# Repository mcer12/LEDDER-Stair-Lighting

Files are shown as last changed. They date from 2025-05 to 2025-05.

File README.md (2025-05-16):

## LEDDER - Motion Triggered Stair Lighting
This was a personal project of mine to make motion triggered stair lights. It uses custom designed PCBs and 3D models, so I wouldn't call it beginner friendly. Feel free to use any of this for your own project.

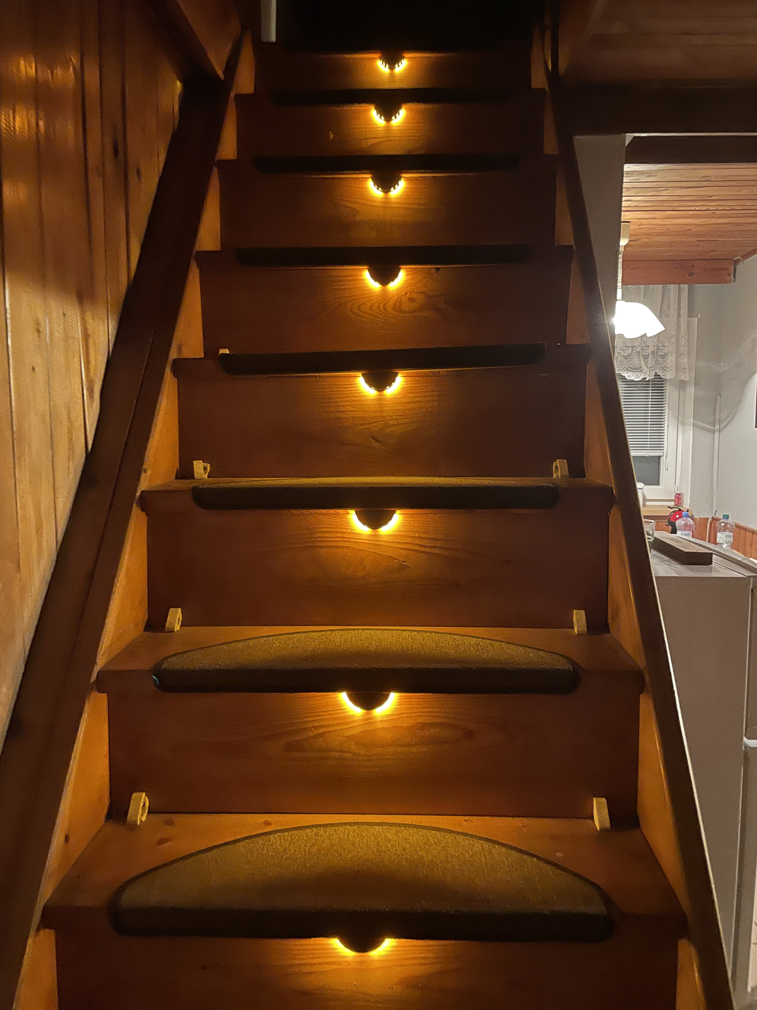
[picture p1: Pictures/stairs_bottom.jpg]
Your image title


### Main points of this project
- Very warm, 2000K LEDs ([C5440671](https://lcsc.com/product-detail/LED-Indication-Discrete_XINGLIGHT-XL-3806WWC_C5440671.html?s_z=n_C5440671%2520)) were chosen for cozy feel and to not be harsh on the eyes at night
- Slow fade-in fade-out, dimming is also gamma corrected so it's nicely linear
- Two sensors so it can be triggered when approaching any side of the stairs.
- Motion sensors combined with photoresistors for triggering only when it's dark
- Fuse not only on the control board but also on every step light, each sensor. Safety first.

### Requirements (apart from PCBs, PCB compontents and 3D printing)
- Power supply used is 12V MeanWell LRS-75-12 (the case has screw positions for it)
- 12x M3x5 hot-melt inserts
- 6x M2x5 hot-melt inserts
- 2x M20x1.5 cable gland

### Some notes
- Each light PCB is designed to be broken apart into two half-circle boards
- Two variants of light PCB are added (for 3806 LEDs and for 4008 LEDs), choose 3806 version for the recommended amber LEDs.
- See images to get better idea of how this looks and works

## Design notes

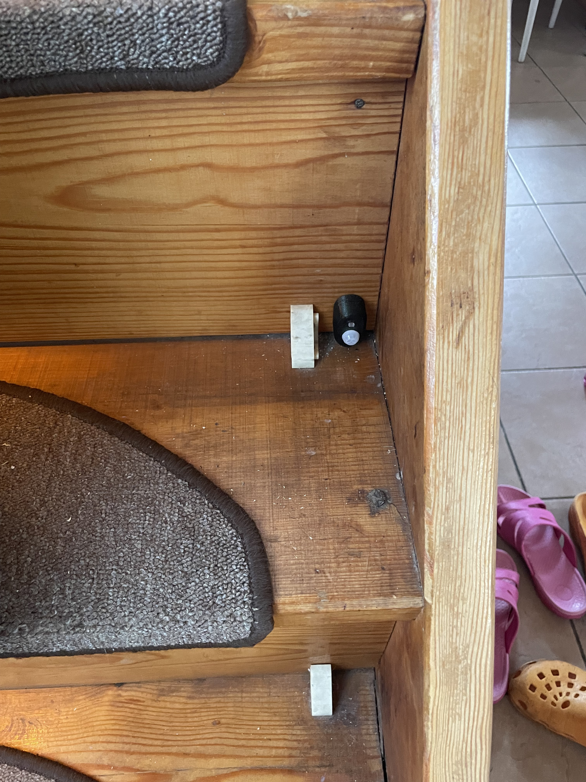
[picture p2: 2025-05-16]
Pictures/imagy-image (6).jpg

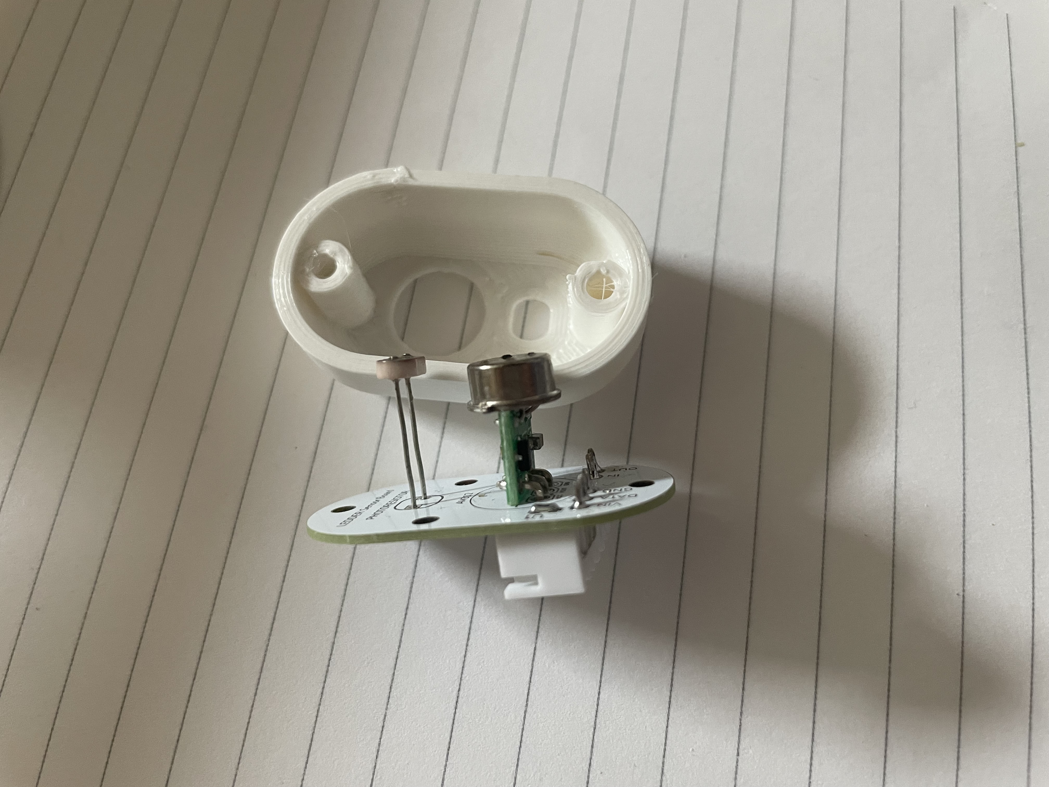
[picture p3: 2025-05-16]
Pictures/imagy-image (3).jpg

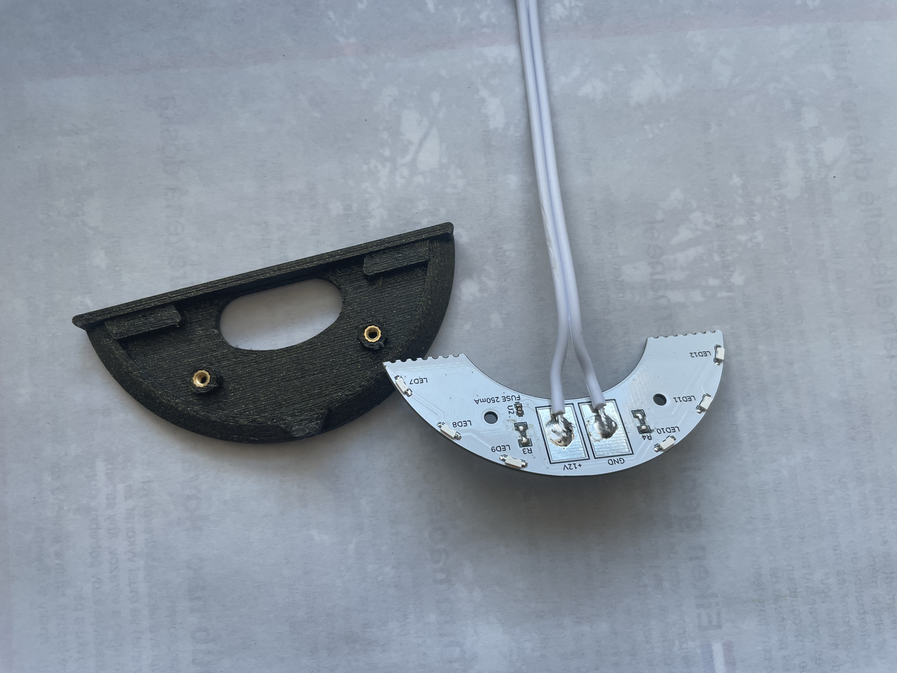
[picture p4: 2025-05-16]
Pictures/imagy-image (1).jpg

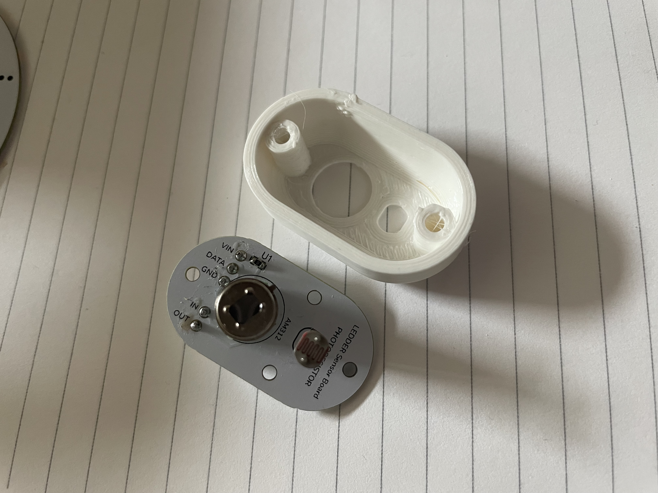
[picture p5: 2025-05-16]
Pictures/imagy-image (2).jpg

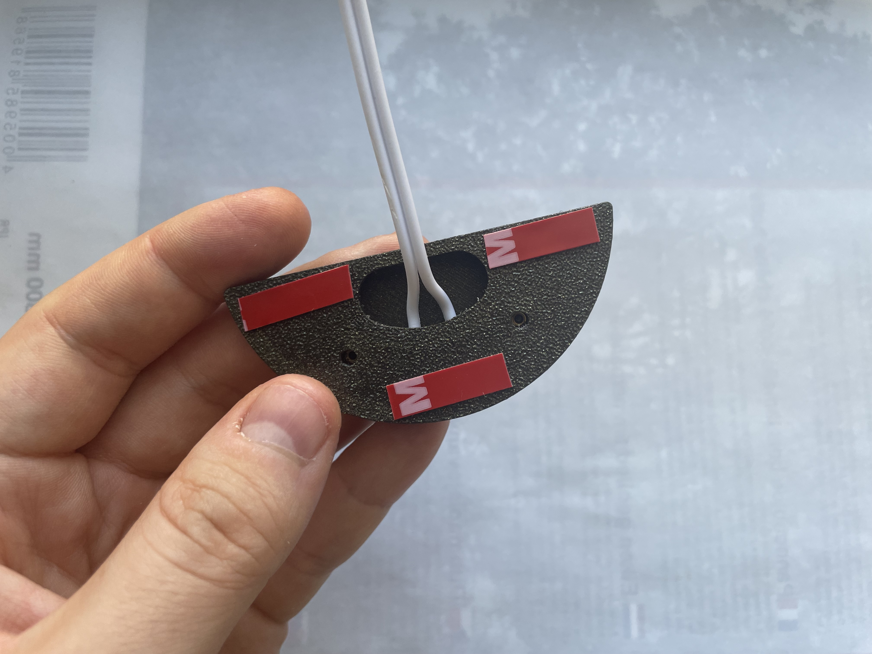
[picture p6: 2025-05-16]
Pictures/imagy-image (4).jpg

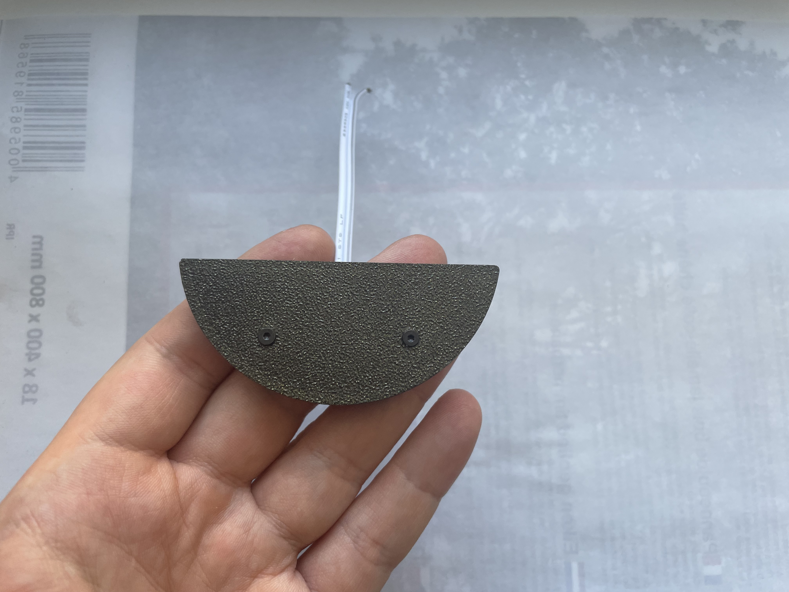
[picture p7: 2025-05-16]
Pictures/imagy-image.jpg

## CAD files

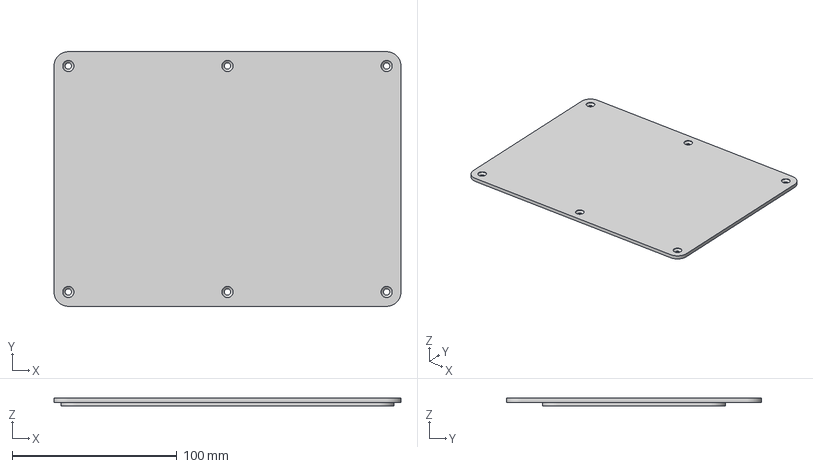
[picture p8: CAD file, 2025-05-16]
Parts/Driver Board/3D Models/box_lid.3mf
210.4 x 154.4 x 4.80 mm

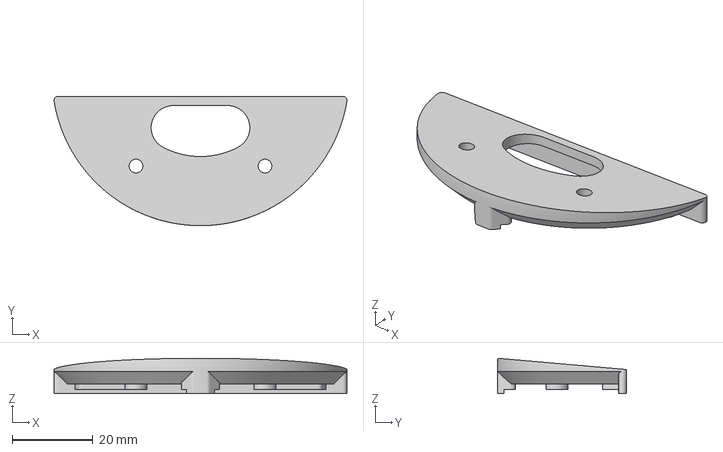
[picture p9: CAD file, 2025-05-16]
Parts/Light/3D Models/light_bottom.3mf
72.7 x 32.1 x 8.80 mm

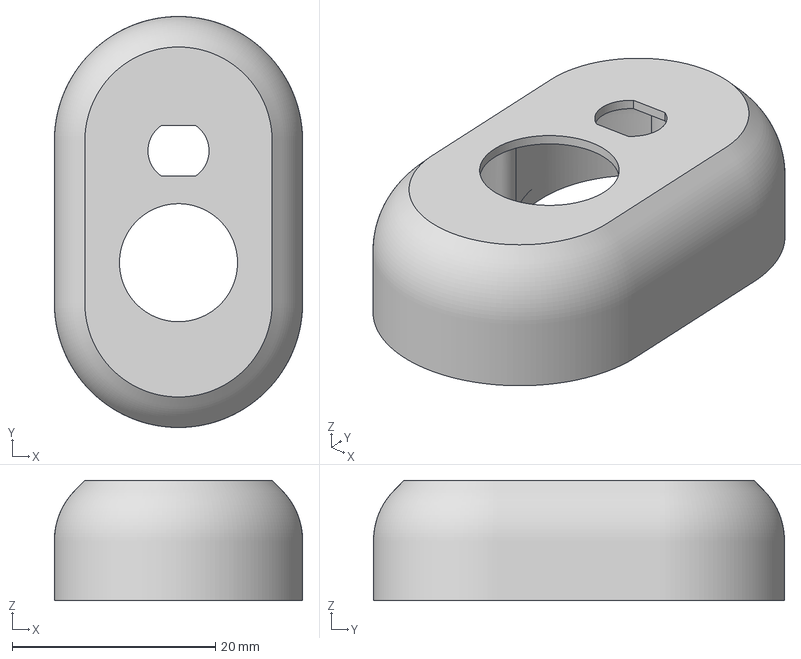
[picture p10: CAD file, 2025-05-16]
Parts/Sensor/3D Models/sensor_top.3mf
24.4 x 40.4 x 11.8 mm

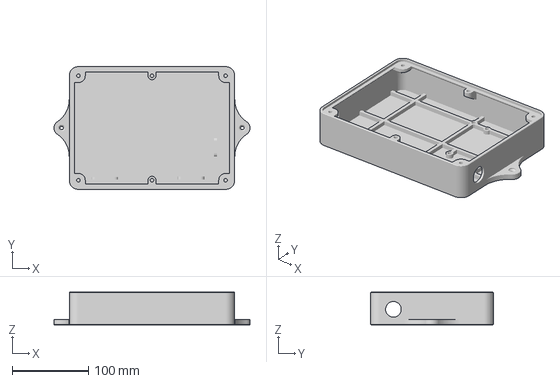
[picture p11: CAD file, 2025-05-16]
Parts/Driver Board/3D Models/box_base.3mf
257.0 x 161.0 x 43.0 mm

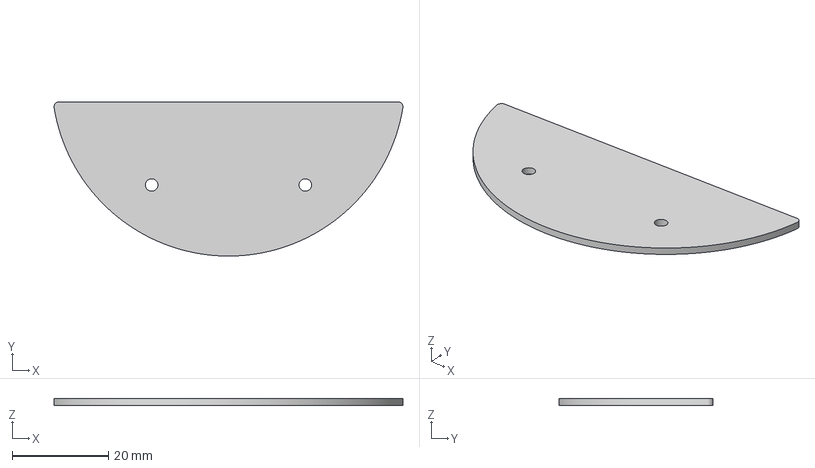
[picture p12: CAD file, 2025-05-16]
Parts/Light/3D Models/light_top.3mf
72.7 x 32.1 x 1.40 mm

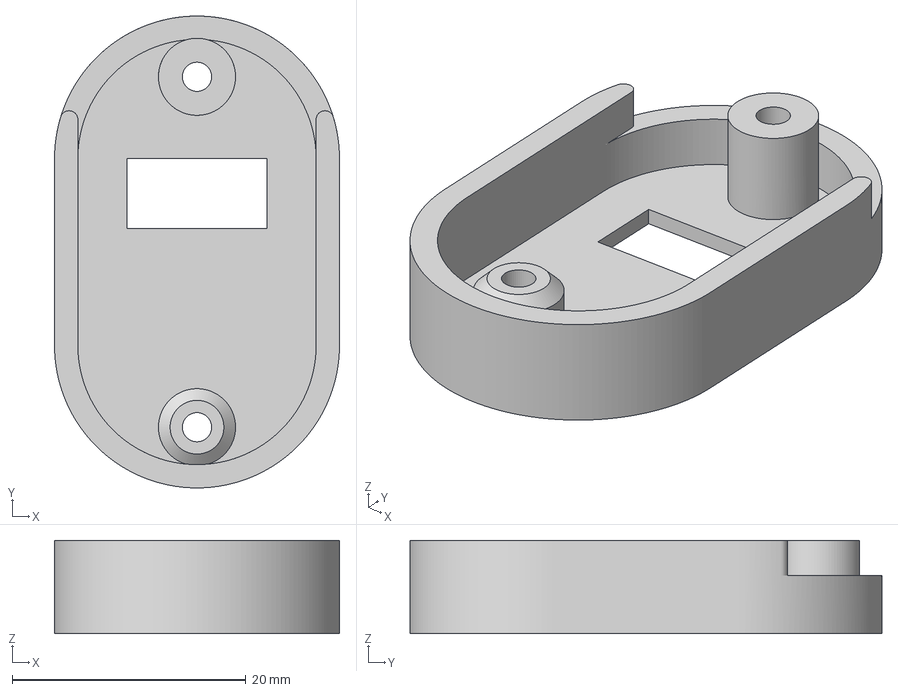
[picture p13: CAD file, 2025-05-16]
Parts/Sensor/3D Models/sensor_bottom.3mf
24.4 x 40.4 x 8.00 mm

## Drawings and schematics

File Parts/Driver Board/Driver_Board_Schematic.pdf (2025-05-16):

## Don't use timer16 and timer17 on stm32G030 for pwm TIM16: PA6, PB6, PB8

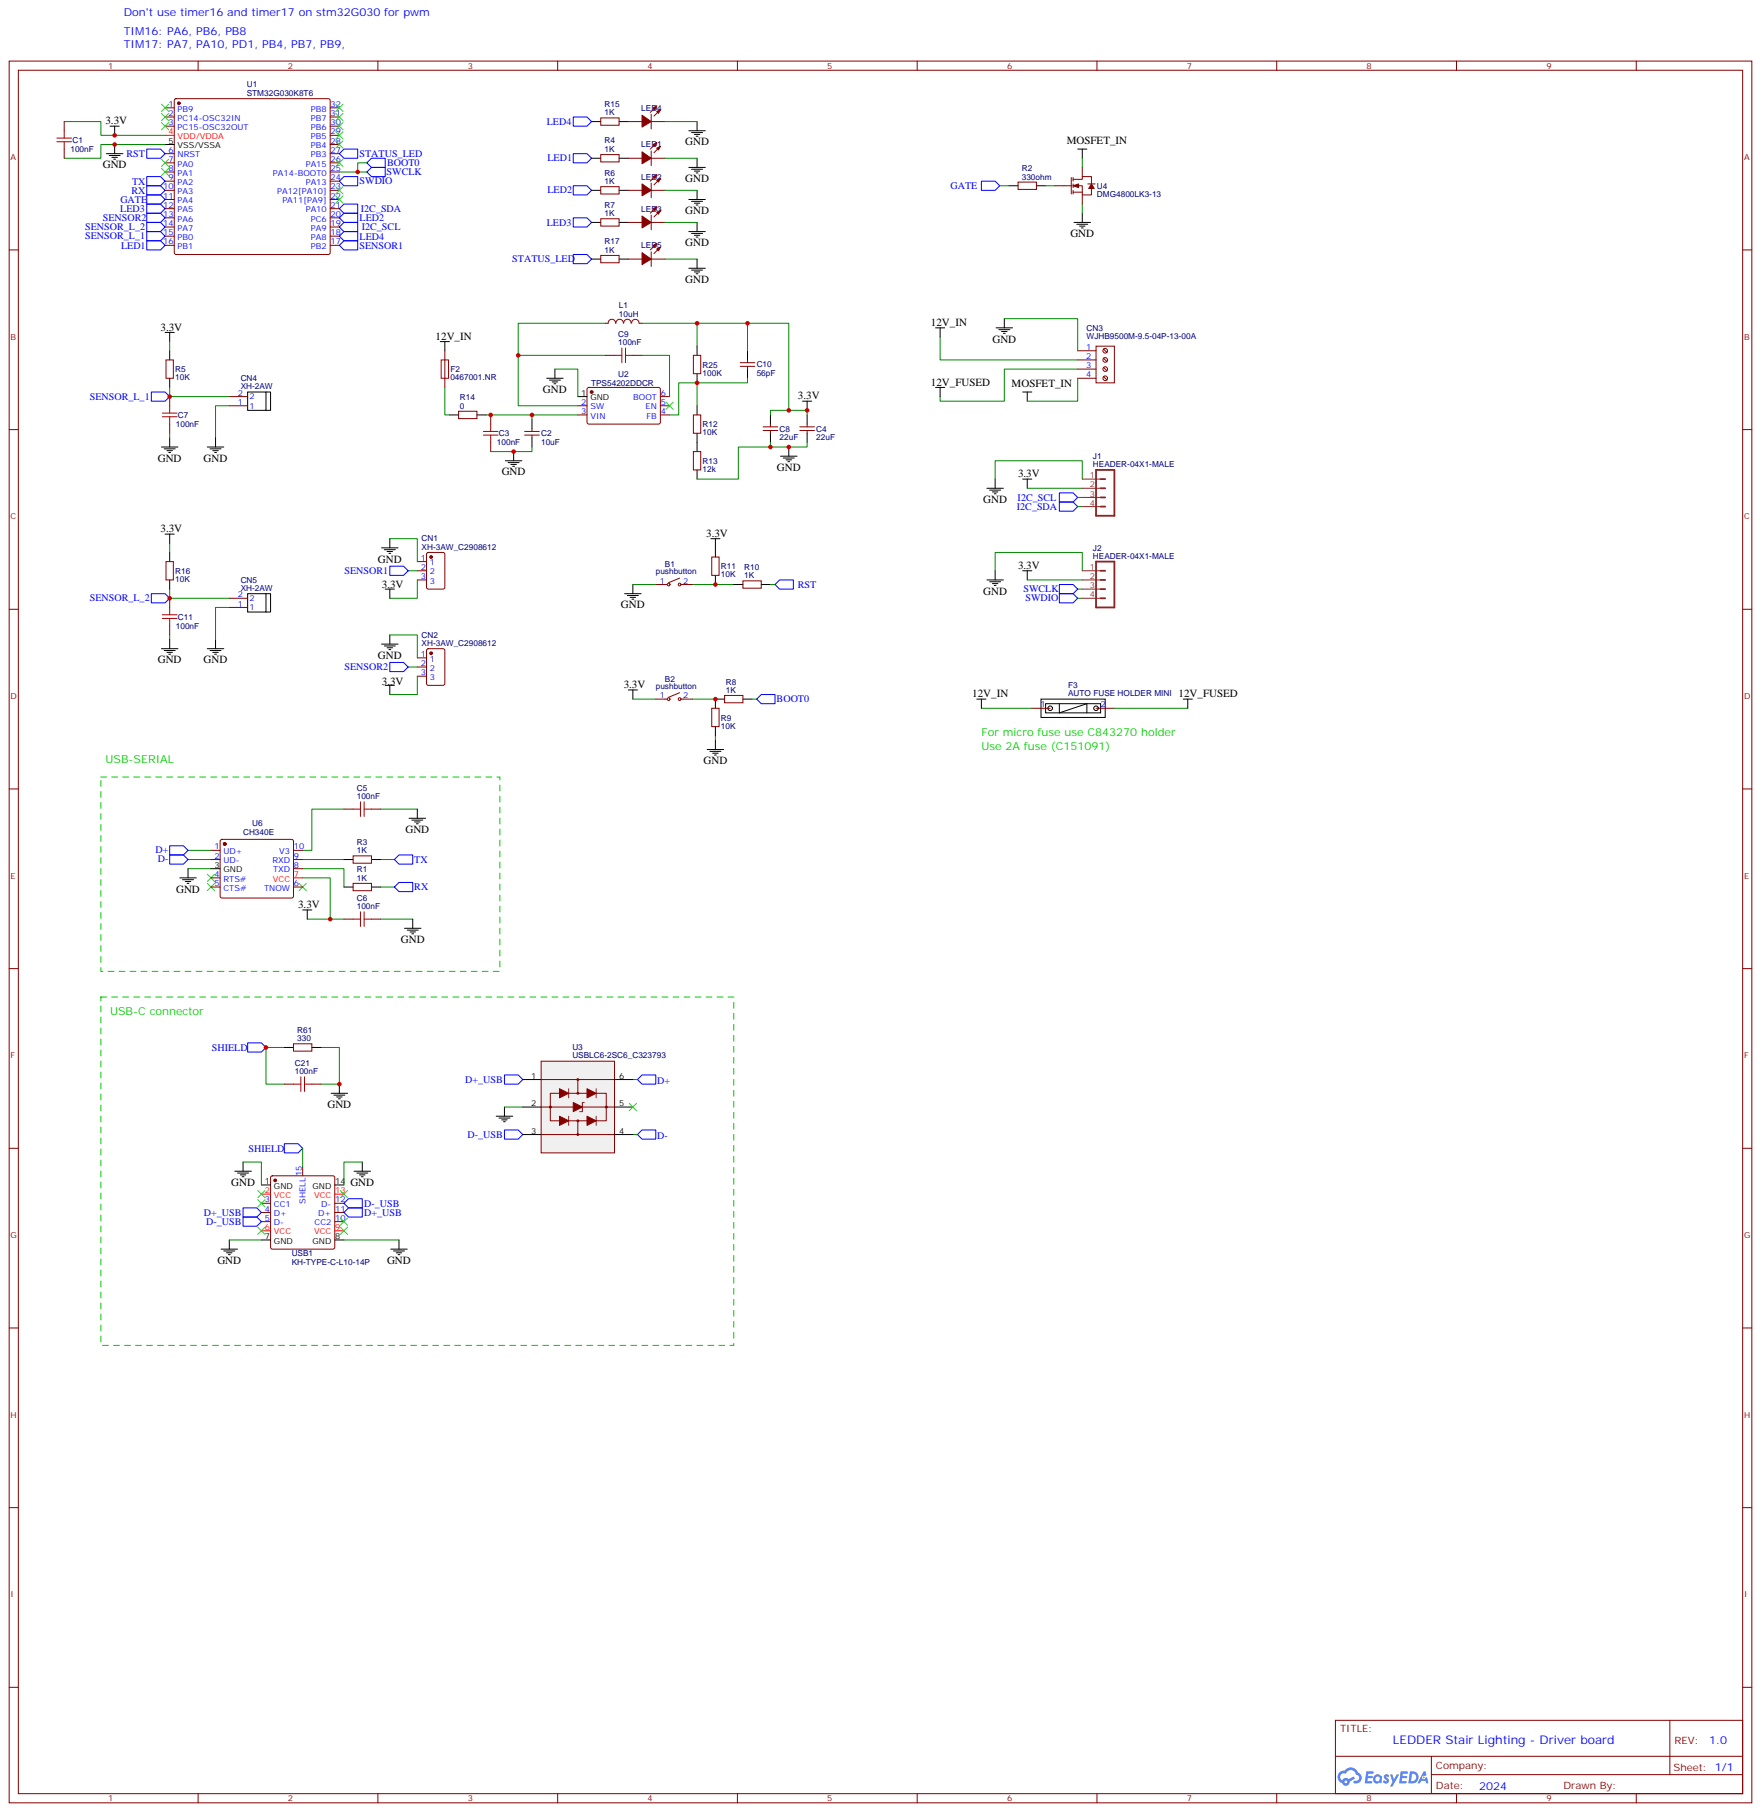
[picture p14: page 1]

AUTO FUSE HOLDER MINI

For micro fuse use C843270 holder
Use 2A fuse (C151091)

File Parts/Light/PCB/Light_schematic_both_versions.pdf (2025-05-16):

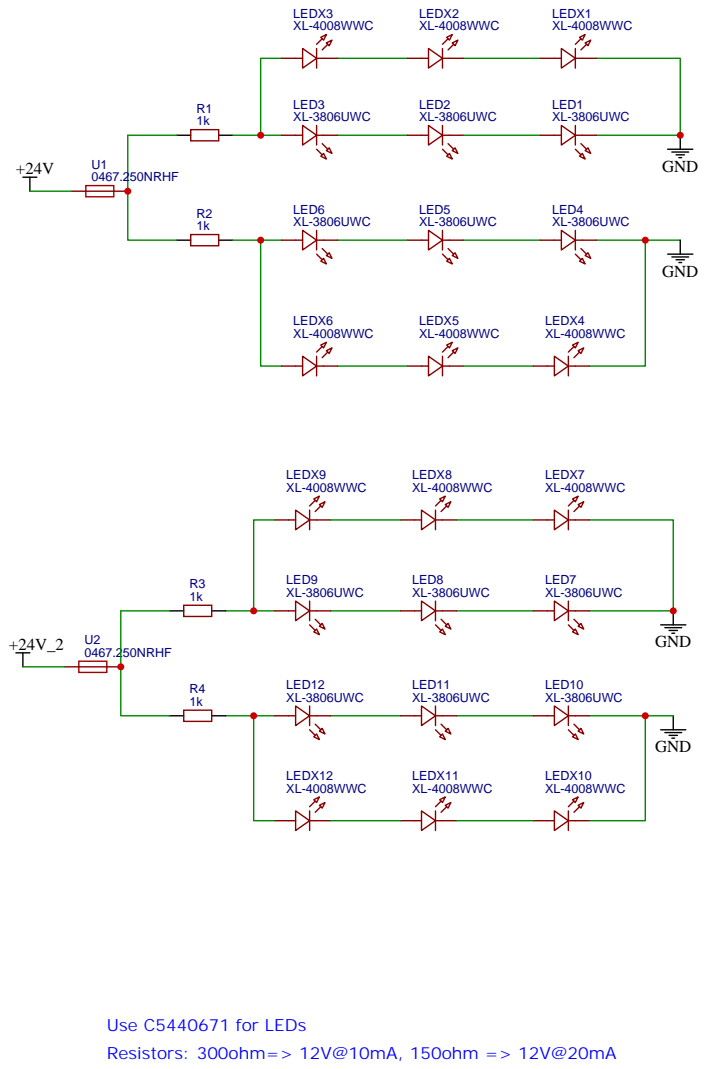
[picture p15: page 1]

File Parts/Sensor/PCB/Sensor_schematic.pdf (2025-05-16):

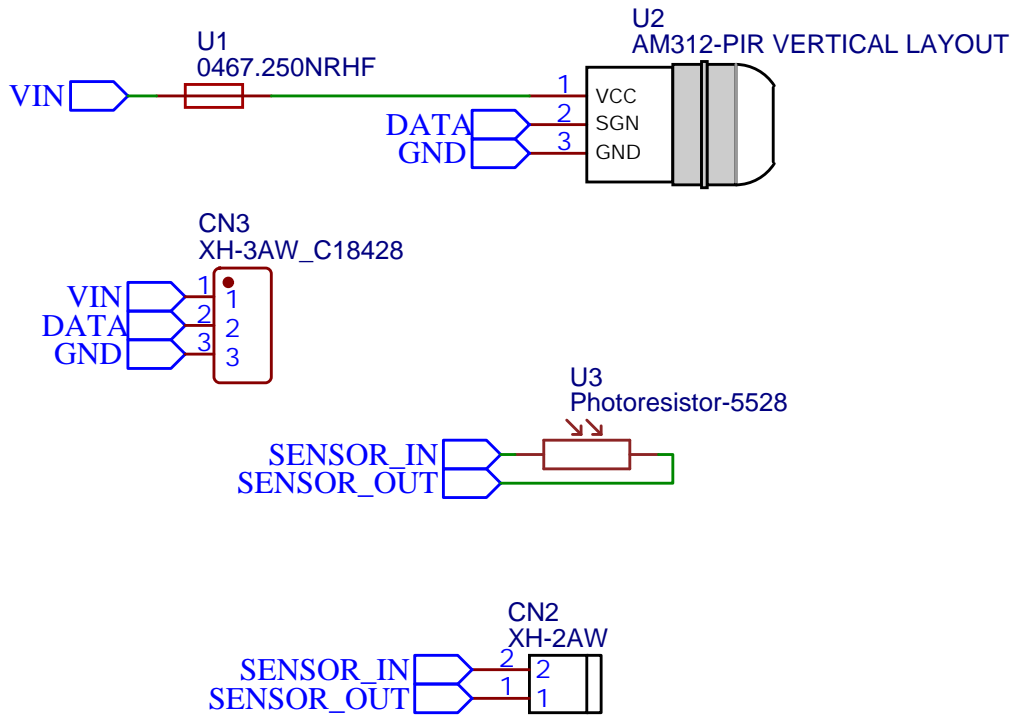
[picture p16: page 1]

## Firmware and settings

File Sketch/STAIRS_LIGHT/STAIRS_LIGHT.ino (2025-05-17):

const uint16_t CIE8[256] = {
  0,    2,    4,    5,    7,    9,   11,   12,   14,   16,   18,   20,   21,   23,   25,   27,
  28,   30,   32,   34,   36,   37,   39,   41,   43,   45,   47,   49,   52,   54,   56,   59,
  61,   64,   66,   69,   72,   75,   77,   80,   83,   87,   90,   93,   96,  100,  103,  107,
  111,  115,  118,  122,  126,  131,  135,  139,  144,  148,  153,  157,  162,  167,  172,  177,
  182,  187,  193,  198,  204,  209,  215,  221,  227,  233,  239,  246,  252,  259,  265,  272,
  279,  286,  293,  300,  308,  315,  323,  330,  338,  346,  354,  362,  371,  379,  388,  396,
  405,  414,  423,  432,  442,  451,  461,  470,  480,  490,  501,  511,  521,  532,  543,  553,
  564,  576,  587,  598,  610,  622,  634,  646,  658,  670,  683,  695,  708,  721,  734,  748,
  761,  775,  788,  802,  816,  831,  845,  860,  874,  889,  904,  920,  935,  951,  966,  982,
  999, 1015, 1031, 1048, 1065, 1082, 1099, 1116, 1134, 1152, 1170, 1188, 1206, 1224, 1243, 1262,
  1281, 1300, 1320, 1339, 1359, 1379, 1399, 1420, 1440, 1461, 1482, 1503, 1525, 1546, 1568, 1590,
  1612, 1635, 1657, 1680, 1703, 1726, 1750, 1774, 1797, 1822, 1846, 1870, 1895, 1920, 1945, 1971,
  1996, 2022, 2048, 2074, 2101, 2128, 2155, 2182, 2209, 2237, 2265, 2293, 2321, 2350, 2378, 2407,
  2437, 2466, 2496, 2526, 2556, 2587, 2617, 2648, 2679, 2711, 2743, 2774, 2807, 2839, 2872, 2905,
  2938, 2971, 3005, 3039, 3073, 3107, 3142, 3177, 3212, 3248, 3283, 3319, 3356, 3392, 3429, 3466,
  3503, 3541, 3578, 3617, 3655, 3694, 3732, 3772, 3811, 3851, 3891, 3931, 3972, 4012, 4054, 4095,
};
/*
  const uint16_t CIE12[1501] = {
  0, 0, 1, 1, 1, 2, 2, 2, 2, 3,
  3, 3, 4, 4, 4, 5, 5, 5, 5, 6,
  6, 6, 7, 7, 7, 8, 8, 8, 8, 9,
  9, 9, 10, 10, 10, 11, 11, 11, 11, 12,
  12, 12, 13, 13, 13, 14, 14, 14, 15, 15,
  15, 15, 16, 16, 16, 17, 17, 17, 18, 18,
  18, 18, 19, 19, 19, 20, 20, 20, 21, 21,
  21, 21, 22, 22, 22, 23, 23, 23, 24, 24,
  24, 25, 25, 25, 25, 26, 26, 26, 27, 27,
  27, 28, 28, 28, 28, 29, 29, 29, 30, 30,
  30, 31, 31, 31, 31, 32, 32, 32, 33, 33,
  33, 34, 34, 34, 34, 35, 35, 35, 36, 36,
  36, 37, 37, 37, 37, 38, 38, 38, 39, 39,
  39, 40, 40, 40, 41, 41, 41, 42, 42, 42,
  43, 43, 43, 44, 44, 44, 45, 45, 45, 46,
  46, 46, 47, 47, 48, 48, 48, 49, 49, 49,
  50, 50, 50, 51, 51, 52, 52, 52, 53, 53,
  54, 54, 54, 55, 55, 56, 56, 56, 57, 57,
  58, 58, 58, 59, 59, 60, 60, 61, 61, 61,
  62, 62, 63, 63, 64, 64, 64, 65, 65, 66,
  66, 67, 67, 68, 68, 68, 69, 69, 70, 70,
  71, 71, 72, 72, 73, 73, 74, 74, 75, 75,
  76, 76, 77, 77, 78, 78, 79, 79, 80, 80,
  81, 81, 82, 82, 83, 83, 84, 84, 85, 85,
  86, 87, 87, 88, 88, 89, 89, 90, 90, 91,
  91, 92, 93, 93, 94, 94, 95, 95, 96, 97,
  97, 98, 98, 99, 100, 100, 101, 101, 102, 103,
  103, 104, 104, 105, 106, 106, 107, 107, 108, 109,
  109, 110, 111, 111, 112, 112, 113, 114, 114, 115,
  116, 116, 117, 118, 118, 119, 120, 120, 121, 122,
  122, 123, 124, 124, 125, 126, 127, 127, 128, 129,
  129, 130, 131, 131, 132, 133, 134, 134, 135, 136,
  137, 137, 138, 139, 139, 140, 141, 142, 142, 143,
  144, 145, 145, 146, 147, 148, 149, 149, 150, 151,
  152, 152, 153, 154, 155, 156, 156, 157, 158, 159,
  160, 160, 161, 162, 163, 164, 165, 165, 166, 167,
  168, 169, 170, 170, 171, 172, 173, 174, 175, 176,
  176, 177, 178, 179, 180, 181, 182, 183, 183, 184,
  185, 186, 187, 188, 189, 190, 191, 192, 193, 193,
  194, 195, 196, 197, 198, 199, 200, 201, 202, 203,
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
  };

  const uint16_t CIE[1024] = {
  0,    7,   14,   21,   28,   35,   43,   50,   57,   64,   71,   78,   85,   92,   99,  106,
  113,  121,  128,  135,  142,  149,  156,  163,  170,  177,  184,  191,  199,  206,  213,  220,
  227,  234,  241,  248,  255,  262,  269,  277,  284,  291,  298,  305,  312,  319,  326,  333,
  340,  348,  355,  362,  369,  376,  383,  390,  397,  404,  411,  418,  426,  433,  440,  447,
  454,  461,  468,  475,  482,  489,  496,  504,  511,  518,  525,  532,  539,  546,  553,  560,
  567,  574,  582,  589,  596,  603,  610,  617,  624,  631,  638,  648,  655,  663,  671,  679,
  687,  695,  703,  711,  719,  727,  735,  744,  752,  761,  769,  778,  786,  795,  804,  813,
  822,  831,  840,  849,  858,  867,  876,  886,  895,  905,  914,  924,  934,  943,  953,  963,
  973,  983,  993, 1004, 1014, 1024, 1034, 1045, 1055, 1066, 1077, 1087, 1098, 1109, 1120, 1131,
  1142, 1153, 1165, 1176, 1187, 1199, 1210, 1222, 1234, 1245, 1257, 1269, 1281, 1293, 1305, 1318,
  1330, 1342, 1355, 1367, 1380, 1392, 1405, 1418, 1431, 1444, 1457, 1470, 1483, 1497, 1510, 1523,
  1537, 1551, 1564, 1578, 1592, 1606, 1620, 1634, 1648, 1662, 1677, 1691, 1706, 1720, 1735, 1750,
  1765, 1780, 1795, 1810, 1825, 1840, 1855, 1871, 1886, 1902, 1918, 1933, 1949, 1965, 1981, 1997,
  2014, 2030, 2046, 2063, 2079, 2096, 2113, 2130, 2146, 2163, 2181, 2198, 2215, 2232, 2250, 2267,
  2285, 2303, 2321, 2338, 2356, 2375, 2393, 2411, 2429, 2448, 2466, 2485, 2504, 2523, 2542, 2561,
  2580, 2599, 2618, 2638, 2657, 2677, 2697, 2716, 2736, 2756, 2776, 2796, 2817, 2837, 2858, 2878,
  2899, 2920, 2941, 2961, 2983, 3004, 3025, 3046, 3068, 3089, 3111, 3133, 3155, 3177, 3199, 3221,
  3243, 3266, 3288, 3311, 3333, 3356, 3379, 3402, 3425, 3448, 3472, 3495, 3519, 3542, 3566, 3590,
  3614, 3638, 3662, 3686, 3711, 3735, 3760, 3784, 3809, 3834, 3859, 3884, 3910, 3935, 3960, 3986,
  4012, 4037, 4063, 4089, 4115, 4142, 4168, 4194, 4221, 4248, 4274, 4301, 4328, 4356, 4383, 4410,
  4438, 4465, 4493, 4521, 4549, 4577, 4605, 4633, 4661, 4690, 4719, 4747, 4776, 4805, 4834, 4863,
  4893, 4922, 4952, 4981, 5011, 5041, 5071, 5101, 5131, 5162, 5192, 5223, 5254, 5285, 5316, 5347,
  5378, 5409, 5441, 5472, 5504, 5536, 5568, 5600, 5632, 5664, 5697, 5729, 5762, 5795, 5828, 5861,
  5894, 5928, 5961, 5995, 6028, 6062, 6096, 6130, 6164, 6199, 6233, 6268, 6302, 6337, 6372, 6407,
  6442, 6478, 6513, 6549, 6585, 6621, 6657, 6693, 6729, 6765, 6802, 6839, 6875, 6912, 6949, 6986,
  7024, 7061, 7099, 7137, 7174, 7212, 7250, 7289, 7327, 7366, 7404, 7443, 7482, 7521, 7560, 7600,
  7639, 7679, 7718, 7758, 7798, 7838, 7879, 7919, 7960, 8000, 8041, 8082, 8123, 8165, 8206, 8248,
  8289, 8331, 8373, 8415, 8457, 8500, 8542, 8585, 8628, 8671, 8714, 8757, 8800, 8844, 8887, 8931,
  8975, 9019, 9064, 9108, 9152, 9197, 9242, 9287, 9332, 9377, 9423, 9468, 9514, 9560, 9606, 9652,
  9698, 9745, 9791, 9838, 9885, 9932, 9979, 10026, 10074, 10121, 10169, 10217, 10265, 10313, 10362, 10410,
  10459, 10508, 10557, 10606, 10655, 10704, 10754, 10804, 10854, 10904, 10954, 11004, 11055, 11105, 11156, 11207,
  11258, 11310, 11361, 11413, 11464, 11516, 11568, 11620, 11673, 11725, 11778, 11831, 11884, 11937, 11990, 12044,
  12097, 12151, 12205, 12259, 12314, 12368, 12423, 12477, 12532, 12587, 12643, 12698, 12754, 12809, 12865, 12921,
  12977, 13034, 13090, 13147, 13204, 13261, 13318, 13375, 13433, 13491, 13548, 13606, 13665, 13723, 13781, 13840,
  13899, 13958, 14017, 14077, 14136, 14196, 14256, 14316, 14376, 14436, 14497, 14557, 14618, 14679, 14740, 14802,
  14863, 14925, 14987, 15049, 15111, 15173, 15236, 15299, 15362, 15425, 15488, 15551, 15615, 15679, 15743, 15807,
  15871, 15935, 16000, 16065, 16130, 16195, 16260, 16326, 16392, 16457, 16523, 16590, 16656, 16723, 16789, 16856,
  16923, 16991, 17058, 17126, 17194, 17261, 17330, 17398, 17467, 17535, 17604, 17673, 17742, 17812, 17881, 17951,
  18021, 18091, 18162, 18232, 18303, 18374, 18445, 18516, 18588, 18659, 18731, 18803, 18875, 18947, 19020, 19093,
  19166, 19239, 19312, 19385, 19459, 19533, 19607, 19681, 19755, 19830, 19905, 19980, 20055, 20130, 20206, 20281,
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
  };
*/

/*
  #define LED1 PA0
  #define LED2 PA1
  #define LED3 PA2

  #define MOSFET PA3

  #define SENSOR1 PA5
  #define SENSOR2 PA6
  #define SENSORL PA7
*/

#define LED_S1 PB1
#define LED_SL1 PA5
#define LED_S2 PC6
#define LED_SL2 PA8
#define LED_STATUS PB3

#define MOSFET PA4

#define S1 PB2
#define SL1 PB0
#define S2 PA6
#define SL2 PA7

#define MAX_BRI 255 // out of 255
#define L_THRESHOLD_ENABLE 1300 // out of 4095
#define L_THRESHOLD_DISABLE 1500 // out of 4095
#define AUTO_OFF_DELAY 30000 // 10s
#define TURN_ON_DURATION 1000 // 1s
#define TURN_OFF_DURATION 10000 // 10s

int delayFadeIn = TURN_ON_DURATION / MAX_BRI;
int delayFadeOut = TURN_OFF_DURATION / MAX_BRI;

unsigned long millis_light_started;
bool sensor_1_val, sensor_2_val, sensor_light_1_en, sensor_light_2_en;
int sensor_light_1_val, sensor_light_2_val, current_bri;

// the setup function runs once when you press reset or power the board
void setup() {
  analogWriteFrequency(4000);
  analogWriteResolution(12);
  analogReadResolution(12);

  pinMode(LED_S1, OUTPUT);
  pinMode(LED_SL1, OUTPUT);
  pinMode(LED_S2, OUTPUT);
  pinMode(LED_SL2, OUTPUT);
  pinMode(LED_STATUS, OUTPUT);

  pinMode(MOSFET, OUTPUT);

  pinMode(S1, INPUT_PULLDOWN);
  pinMode(SL1, INPUT);
  pinMode(S2, INPUT_PULLDOWN);
  pinMode(SL2, INPUT);

  Serial.begin(115200);
}

// the loop function runs over and over again forever
void loop() {
  sensor_1_val = digitalRead(S1);
  sensor_2_val = digitalRead(S2);
  sensor_light_1_val = 4095 - analogRead(SL1);
  sensor_light_2_val = 4095 - analogRead(SL2);

  if (sensor_light_1_val < L_THRESHOLD_ENABLE) sensor_light_1_en = true;
  if (sensor_light_1_val > L_THRESHOLD_DISABLE) sensor_light_1_en = false;

  if (sensor_light_2_val < L_THRESHOLD_ENABLE) sensor_light_2_en = true;
  if (sensor_light_2_val > L_THRESHOLD_DISABLE) sensor_light_2_en = false;

  digitalWrite(LED_S1, sensor_1_val);
  digitalWrite(LED_S2, sensor_2_val);
  digitalWrite(LED_SL1, sensor_light_1_en);
  digitalWrite(LED_SL2, sensor_light_2_en);

  if ((sensor_1_val || sensor_2_val) && (sensor_light_1_en || sensor_light_2_en)) {
    millis_light_started = millis();
  }

  //analogWrite(MOSFET, CIE8[1]);
  //analogWrite(LED_STATUS, CIE8[1]);


  if (millis() - millis_light_started <= AUTO_OFF_DELAY) {
    current_bri++;
    if (current_bri > MAX_BRI) current_bri = MAX_BRI;
    analogWrite(MOSFET, CIE8[current_bri]);
    analogWrite(LED_STATUS, CIE8[current_bri]);
    delay(delayFadeIn);
  } else {
    current_bri--;
    if (current_bri < 0) current_bri = 0;
    analogWrite(MOSFET, CIE8[current_bri]);
    analogWrite(LED_STATUS, CIE8[current_bri]);
    delay(delayFadeOut);
  }

  Serial.print("S1: ");
  Serial.print(sensor_1_val);
  Serial.print(", S2: ");
  Serial.print(sensor_2_val);
  Serial.print(", L1: ");
  Serial.println(sensor_light_1_val);
  Serial.print(", L2: ");
  Serial.println(sensor_light_2_val);

}

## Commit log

2025-05-16 Parts sources, 3D files
    [box_base.3mf, box_lid.3mf, light_bottom.3mf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]
2025-05-17 Arduino sketch added
